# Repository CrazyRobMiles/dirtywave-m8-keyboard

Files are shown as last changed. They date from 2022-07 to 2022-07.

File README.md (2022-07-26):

# USB Keyboard and case for Dirtywave M8 Headless

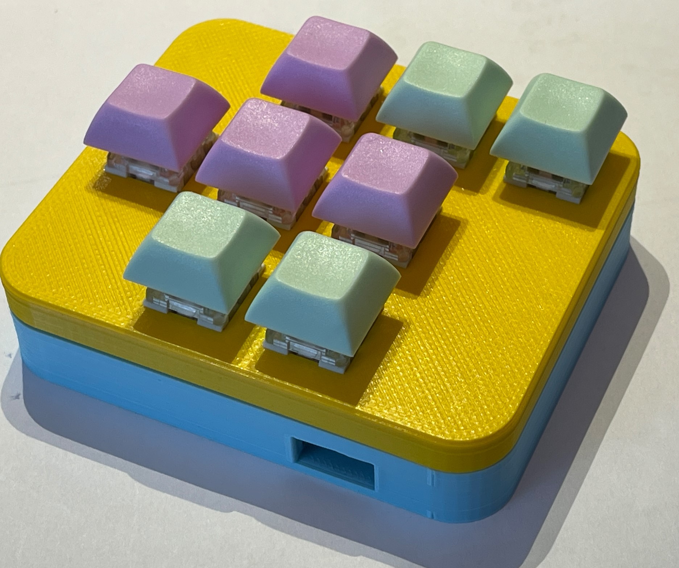
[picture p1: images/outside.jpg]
outside image of the case


This is a little case for the wonderful [Dirtywave M8](http://www.dirtywave.com) headless device. It uses a Raspberry Pi Pico to simulate a 
USB keyboard and also serves as a case for the Teensy 4.1 that powers the whole system. The back has two holes for USB connectors. You just plug them both into your computer and you have the Teensy running and a clicky keyboard that works just like the real thing. 

There are 3D printable designs for the case. You can use Kailh Mechanical Keyboard Switches if you're not afraid to solder directly to the pins on the back. There are designs for just the keyboard Pico or both the Pico and the Teensy. 

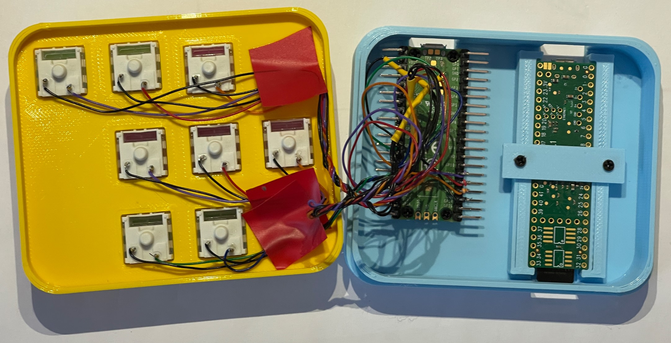
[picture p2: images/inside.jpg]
inside image of the case


I used wire wrap wires to connect the Pico to the switches. They are wire wrapped onto solder pins on the Pic and and then wire wrapped and soldered onto the switches. Not pretty, but this is only a problem if you let someone look inside. If anyone fancies making a PCB you have my full support :) 

```python
key_switches = [
        Switch(pin=board.GP18,name="up",ch=Keycode.UP_ARROW),      # up
        Switch(pin=board.GP19,name="option",ch=Keycode.Z),  # option
        Switch(pin=board.GP20,name="Edit",ch=Keycode.X),    # edit 
        Switch(pin=board.GP13,name="Left",ch=Keycode.LEFT_ARROW),    # left
        Switch(pin=board.GP12,name="down",ch=Keycode.DOWN_ARROW),    # down
        Switch(pin=board.GP11,name="right",ch=Keycode.RIGHT_ARROW),   # right
        Switch(pin=board.GP21,name="shift",ch=Keycode.LEFT_SHIFT),   # shift 
        Switch(pin=board.GP22,name="play",ch=Keycode.SPACEBAR)   # play
        ]
```

Above are the pin assignmnents I used for each key to GPIO pins on the Pico. All the switches should pull the input to ground. 

The Teensy is clamped inside the case. There are no connections to it. The idea is that we should get some airflow along the bottom of the case to keep it cool. 

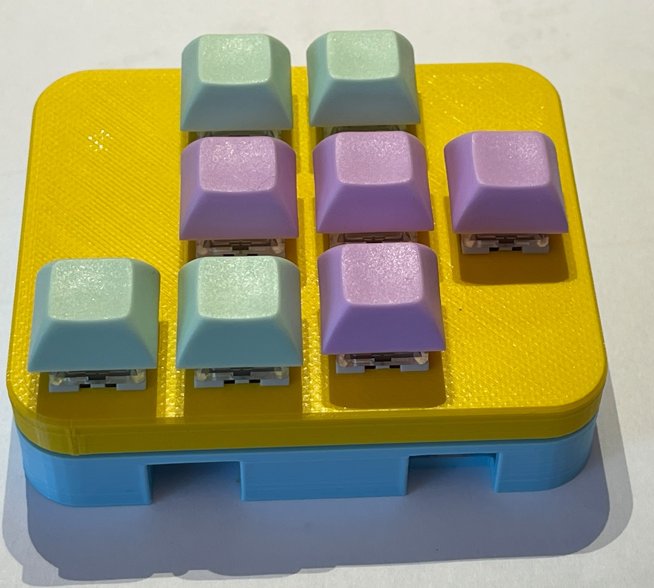
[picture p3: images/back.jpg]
image of the back of the case


The Pico is powered by a Circuit Python program that scans the switches and sends out keypresses. Load Circuit Python 7 onto the device, copy code.py onto the drive along with the contents of the lib folder and you should be good to go. 

Have fun

Rob Miles

http://www.robmiles.com

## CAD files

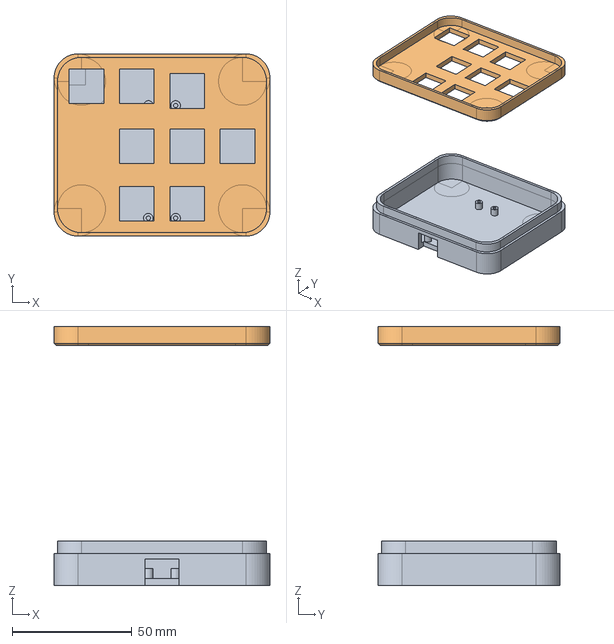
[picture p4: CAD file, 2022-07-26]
case/Case Designs.FCStd
90.0 x 76.0 x 108.0 mm

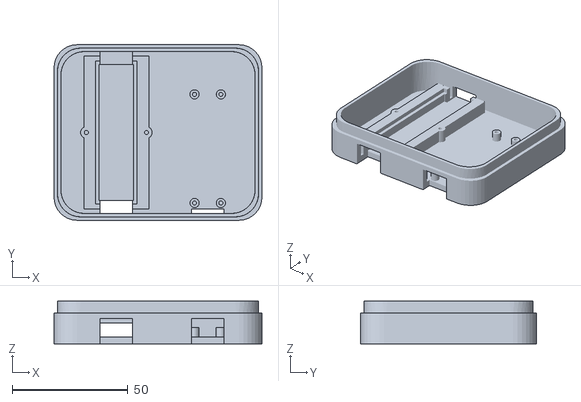
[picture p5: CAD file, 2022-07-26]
case/teensybottom.stl
90.0 x 76.0 x 18.5

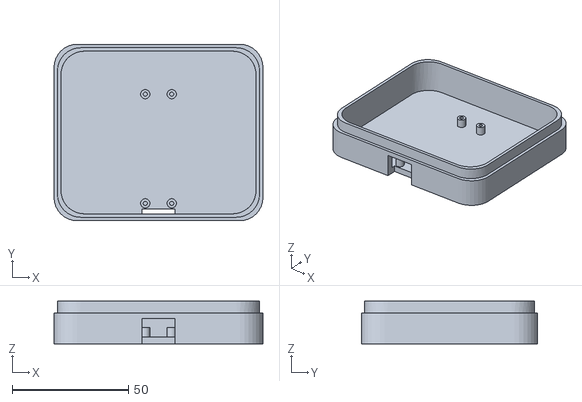
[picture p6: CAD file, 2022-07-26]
case/bottom.stl
90.0 x 76.0 x 18.5

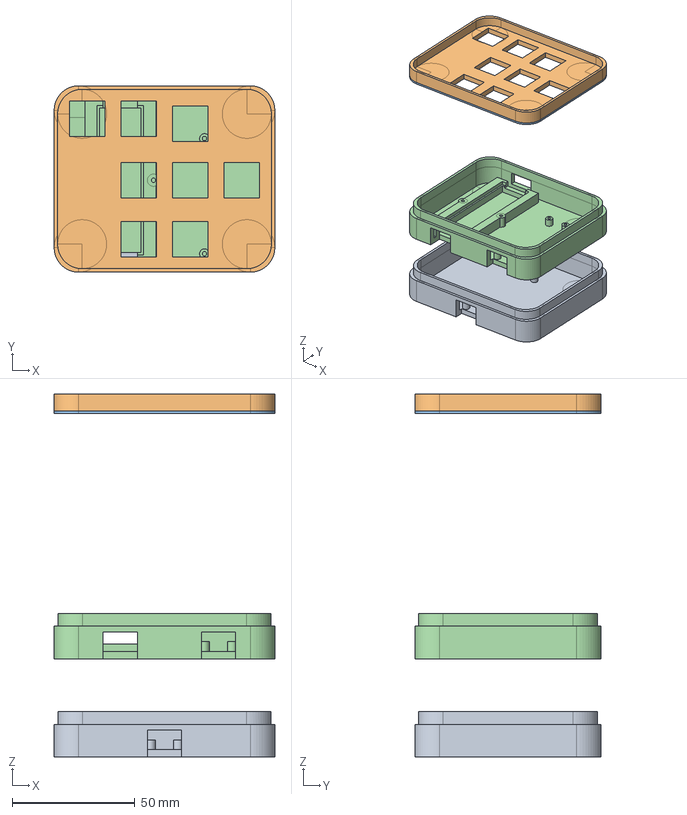
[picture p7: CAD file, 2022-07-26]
case/Case designs with Teensy.FCStd
90.0 x 76.0 x 148.0 mm

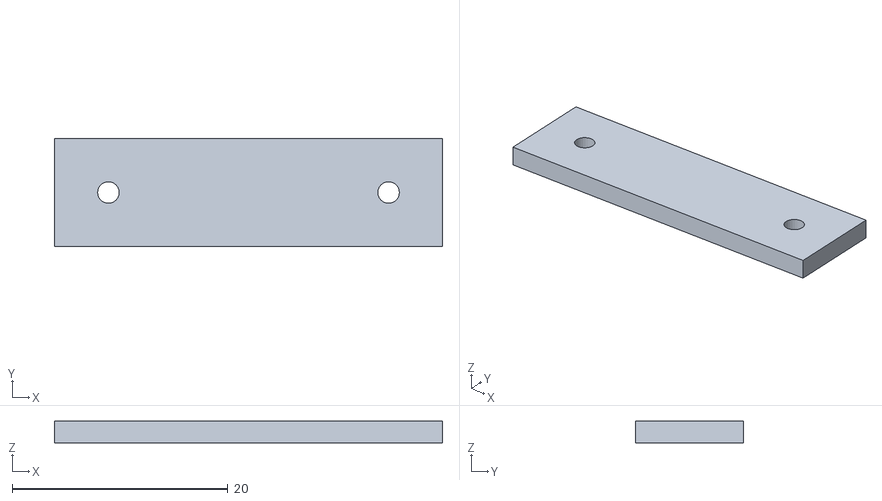
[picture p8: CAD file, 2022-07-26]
case/teensyClamp.stl
36.0 x 10.0 x 2.00

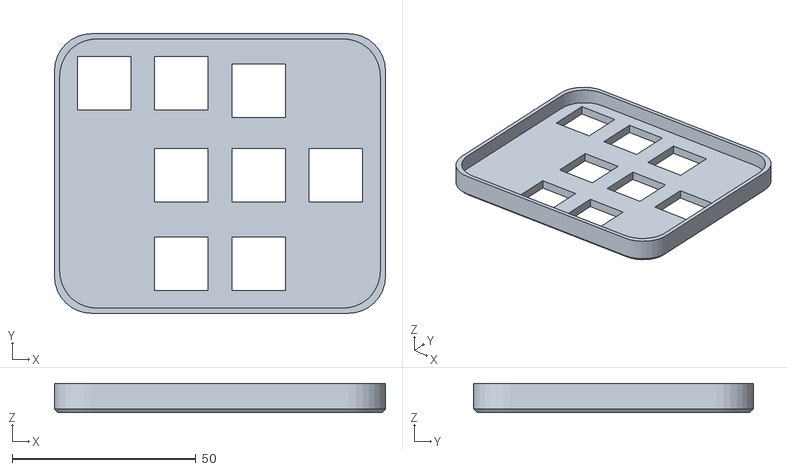
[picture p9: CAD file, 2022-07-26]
case/top.stl
90.0 x 76.0 x 8.00

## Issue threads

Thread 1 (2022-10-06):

Up and Down Not working

andeecollard, 2022-10-06:
Hi Rob,
Fantastic project. I wired it all up and it works but the up and down don't. Is there something I'm missing? I just wired each switch to the GP and an individual ground pin. Do I need to do something else?

Best wishes

Andee

andeecollard, 2022-10-07:
sorry– found the problem two defective switches!

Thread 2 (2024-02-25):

Keys don't seem to control M8 as expected...

yratof, 2024-02-25:
So I know this is a little old project, but i think it's worth adding as an issue for anyone else building this:

I've mapped as follows:

```
key_switches = [
        Switch(pin=board.GP18,name="up",ch=Keycode.UP_ARROW),      # up
        Switch(pin=board.GP19,name="option",ch=Keycode.Z),  # option
        Switch(pin=board.GP20,name="Edit",ch=Keycode.X),    # edit
        Switch(pin=board.GP13,name="Left",ch=Keycode.LEFT_ARROW),    # left
        Switch(pin=board.GP12,name="down",ch=Keycode.DOWN_ARROW),    # down
        Switch(pin=board.GP11,name="right",ch=Keycode.RIGHT_ARROW),   # right
        Switch(pin=board.GP21,name="shift",ch=Keycode.LEFT_SHIFT),   # shift
        Switch(pin=board.GP22,name="play",ch=Keycode.SPACEBAR)   # play
 ]
```

I've testing the keyboard, all the keys correctly do what is stated above.

However, they don't do anything within m8p — shortcuts that should control things like editing don't seem to do they thing they should do:

https://sites.google.com/view/m8tracker/song?authuser=0

Is there anything on the config side of M8p that should be tricked into knowing zxshiftspace etc?

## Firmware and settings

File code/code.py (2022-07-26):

import board
import busio
import time
from digitalio import DigitalInOut, Direction, Pull
from adafruit_debouncer import Debouncer
import usb_hid
from adafruit_hid.keyboard import Keyboard
# Import the keyboard layout description
from adafruit_hid.keyboard_layout_uk import KeyboardLayoutUK

from adafruit_hid.keycode import Keycode

version = "0.0"

class Switch():
    def __init__(self, pin, name, ch): 
        self.pin = pin
        self.name = name
        self.ch = ch
    
class Key():
    def __init__(self, keyboard, switch): 
        self.keyboard = keyboard
        self.switch = switch
        # make a digital io from the pin
        io = DigitalInOut(self.switch.pin)
        # add a pullup
        io.pull = Pull.UP
        # create the key debouncer
        self.debounce = Debouncer(io,interval=0.01)
        self.debounce.update()
        self.pressed = not self.debounce.value

    def update(self):
        debounce = self.debounce
        debounce.update()
        if debounce.fell:
            self.key_down()
        if debounce.rose:
            self.key_up()
            
    def key_down(self):
        print("key:",self.switch.name,"down")
        keyboard = self.keyboard
        keyboard.press(self.switch.ch)
        self.pressed = True
    
    def key_up(self):
        keyboard = self.keyboard
        print("key:",self.switch.name,"up")
        keyboard.release(self.switch.ch)
        self.pressed = False
            
class DirtywaveKeys:
    def __init__(self, key_switches):
        hello_message = "Dirtwave M8 keyboard " + str(version)
        print(hello_message)
        #
        self.usb_kbd = Keyboard(usb_hid.devices)
        # Set the required keyboard layout
        self.usb_layout = KeyboardLayoutUK(self.usb_kbd)
        #
        # Create the array of keys
        self.keys = []
        # going to use a mask bit for each key to assemble a key pattern
        for switch in key_switches:
            # Make the key
            key = Key(keyboard=self.usb_kbd,switch=switch)
            # add it to the list of keys
            self.keys.append(key)
        
        self.wait_for_all_keys_up()
        
    def key_down(self):
        for key in self.keys:
            # get the key debouncer
            debounce = key.debounce
            debounce.update()
            if not debounce.value:
                return True
        return False
        
    def wait_for_all_keys_up(self):
        while True:
            if self.key_down():
                continue
            return
        
    def test(self):
        print("Test")        
        while True:
            # scan the keyboard and turn pressed keys red
            for key in self.keys:
                # get the key debouncer
                debounce = key.debounce
                debounce.update()
                if debounce.fell:
                    print("Key down:", key.switch.name)
                if debounce.rose:
                    print("Key up:", key.switch.name)
    
    def update_keys(self):
        for key in self.keys:
            key.update()
    
    def update(self):
        self.update_keys()
        
    def run(self):
        while True:
            self.update()
            
key_switches = [
        Switch(pin=board.GP18,name="up",ch=Keycode.UP_ARROW),      # up
        Switch(pin=board.GP19,name="option",ch=Keycode.Z),  # option
        Switch(pin=board.GP20,name="Edit",ch=Keycode.X),    # edit 
        Switch(pin=board.GP13,name="Left",ch=Keycode.LEFT_ARROW),    # left
        Switch(pin=board.GP12,name="down",ch=Keycode.DOWN_ARROW),    # down
        Switch(pin=board.GP11,name="right",ch=Keycode.RIGHT_ARROW),   # right
        Switch(pin=board.GP21,name="shift",ch=Keycode.LEFT_SHIFT),   # shift 
        Switch(pin=board.GP22,name="play",ch=Keycode.SPACEBAR)   # play - h
        ]

keyboard = DirtywaveKeys(key_switches=key_switches)
keyboard.run()
